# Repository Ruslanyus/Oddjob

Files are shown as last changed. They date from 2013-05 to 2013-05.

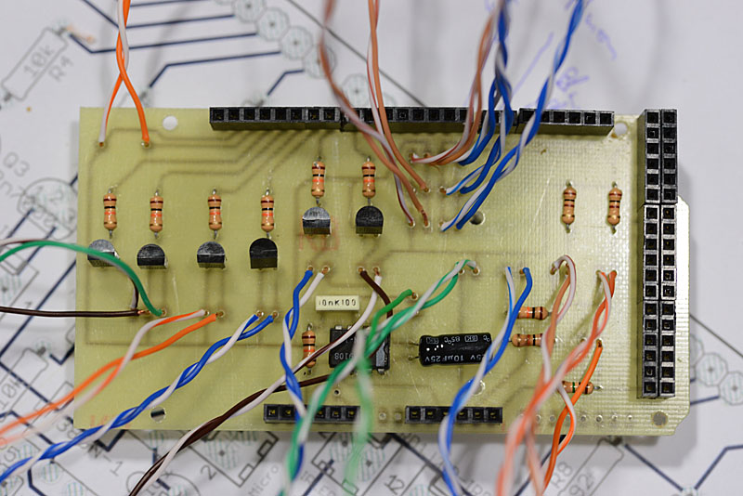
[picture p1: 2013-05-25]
CI-monte-small.jpg

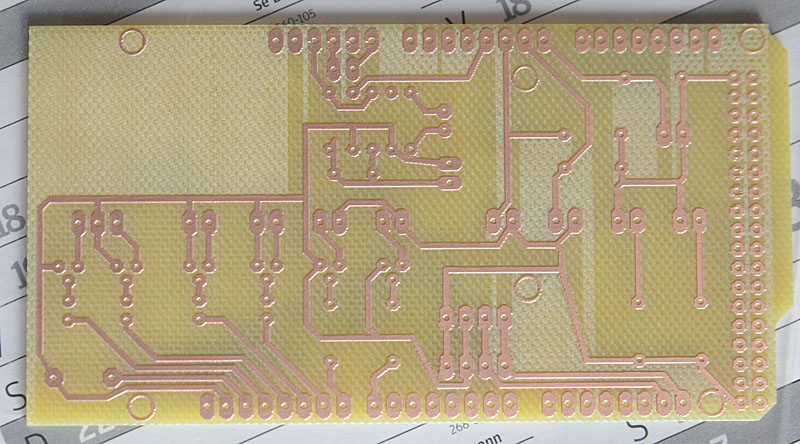
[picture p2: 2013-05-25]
CI-small.jpg

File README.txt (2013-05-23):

Oddjob project is based on the Photoduino project.
My main objective is to add a new interface to this project, I have added a touch screen with several updated.

Logos are stored on the SD card, UTFT library and tools are used to generate logo.

You have to copy logos on RAW format into the root of your SD card.

To do list:
-unbug the display: some case the text is too long and wrote out of display memory, I have to fix this issue

-The date and time module is not coded to log all information with date and time
-luxmeter display information but information is display without presentation.

I publish more information on the www.godreau.fr website with photos.

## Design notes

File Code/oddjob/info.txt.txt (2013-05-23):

arduino port Used:
TFT: 38,39,40,41
touch: 6,5,4,3,2
sd card: D52,50,51+SS

Ports analogics
- sound 4
- ir led1 6
- ir led2 5
- shock 7

ports num:
-buzzer 13
-focus 12
-trigger 11
-flash1 10
-flash2 9
-laser1 8 
-laser2 7

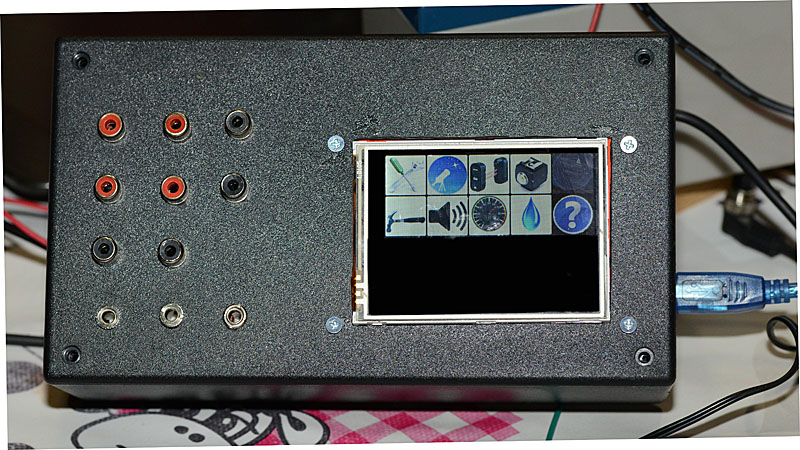
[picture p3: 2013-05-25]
oddjob-small.jpg

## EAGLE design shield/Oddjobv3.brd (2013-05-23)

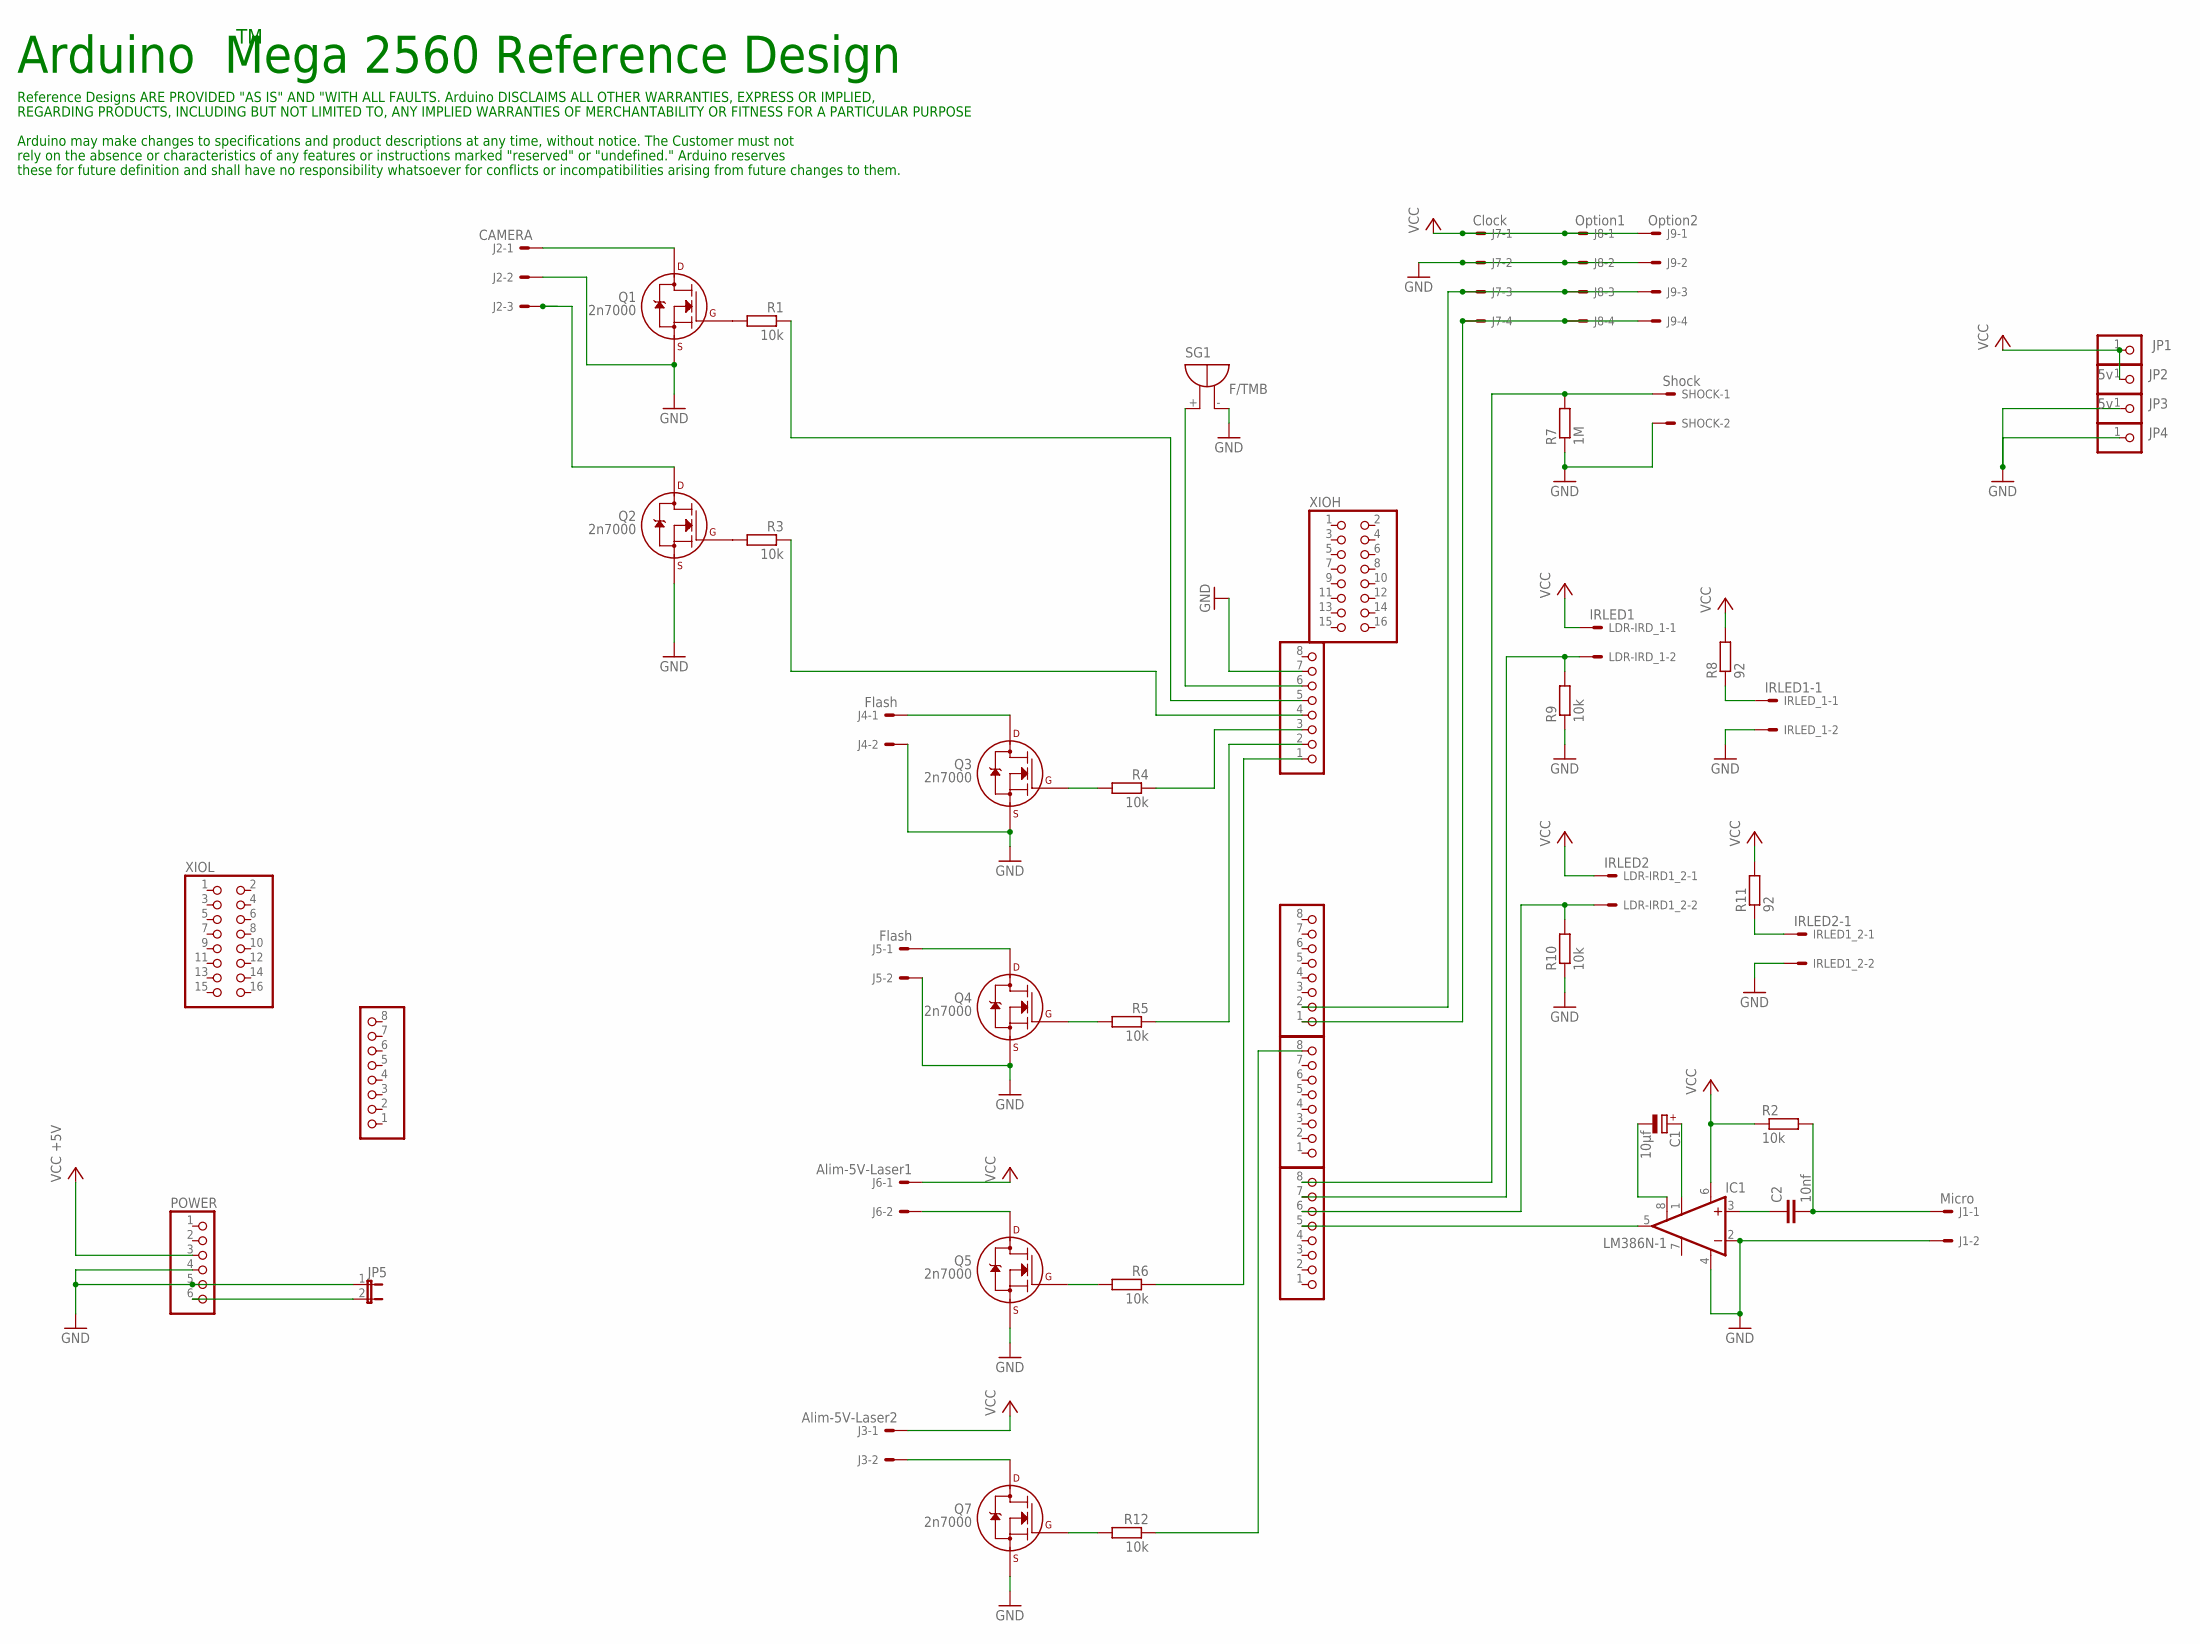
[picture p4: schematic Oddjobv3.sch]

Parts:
ADCH: PINHD-1X8; 1X08
ADCL: PINHD-1X8; 1X08
C1: 10µf; E2,5-6
C2: 10nf; C050-025X075
COMMUNICATION: PINHD-1X8; 1X08
IC1: LM386N-1; DIL08
IRLED1_2: IRLED2-1; 6410-02
IRLED_1: IRLED1-1; 6410-02
J1: Micro; 6410-02
J2: CAMERA; 6410-03
J3: Alim-5V-Laser2; 6410-02
J4, J5: Flash; 6410-02
J6: Alim-5V-Laser1; 6410-02
J7: Clock; 6410-04
J8: Option1; 6410-04
J9: Option2; 6410-04
JP1, JP2: 5v; 1X01
JP3, JP4: PINHD-1X1; 1X01
JP5: JP1E; JP1
LDR-IRD1_2: IRLED2; 6410-02
LDR-IRD_1: IRLED1; 6410-02
POWER: PINHD-1X6; 1X06
PWMH-NUMERIC: PINHD-1X8; 1X08
PWML: PINHD-1X8; 1X08
Q1, Q2, Q3, Q4, Q5, Q7: 2n7000; TO-92
R1, R2, R3, R4, R5, R6, R9, R10, R12: 10k; 0207/7
R7: 1M; 0207/7
R8, R11: 92; 0207/7
SG1: F/TMB
SHOCK: Shock; 6410-02
XIOH: PINHD-2X8; 2X08
XIOL: PINHD-2X8; 2X08

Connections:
GND: IC1.2 (-IN), IC1.4 (GND), IRLED1_2.2, IRLED_1.2, J1.2, J2.2, J4.2, J5.2, J7.2, J8.2, J9.2, JP3.1, JP4.1, JP5.1, POWER.4, POWER.5, PWMH-NUMERIC.7, Q1.1 (S), Q2.1 (S), Q3.1 (S), Q4.1 (S), Q5.1 (S), Q7.1 (S), R7.1, R9.1, R10.1, SG1.-, SHOCK.2
unnamed: Q1.2 (G), R1.2
unnamed: J2.1, Q1.3 (D)
unnamed: C1.+, IC1.1 (GAIN)
unnamed: C1.-, IC1.8 (GAIN)
unnamed: C2.1, IC1.3 (+IN)
unnamed: C2.2, J1.1, R2.2
unnamed: Q2.2 (G), R3.2
unnamed: J2.3, Q2.3 (D)
unnamed: PWMH-NUMERIC.6, SG1.+
unnamed: Q3.2 (G), R4.2
unnamed: J4.1, Q3.3 (D)
unnamed: J6.2, Q5.3 (D)
unnamed: Q4.2 (G), R5.2
unnamed: J5.1, Q4.3 (D)
unnamed: Q5.2 (G), R6.2
unnamed: IRLED_1.1, R8.1
unnamed: ADCL.7, LDR-IRD_1.2, R9.2
unnamed: ADCL.6, LDR-IRD1_2.2, R10.2
unnamed: IRLED1_2.1, R11.1
unnamed: PWMH-NUMERIC.1, R6.1
unnamed: PWMH-NUMERIC.5, R1.1
unnamed: PWMH-NUMERIC.2, R5.1
unnamed: PWMH-NUMERIC.4, R3.1
unnamed: PWMH-NUMERIC.3, R4.1
unnamed: ADCL.5, IC1.5 (OUT)
unnamed: Q7.2 (G), R12.2
unnamed: J3.2, Q7.3 (D)
unnamed: ADCL.8, R7.2, SHOCK.1
unnamed: COMMUNICATION.1, J7.4, J8.4, J9.4
unnamed: PWML.8, R12.1
unnamed: COMMUNICATION.2, J7.3, J8.3, J9.3
unnamed: JP5.2, POWER.6
VCC: IC1.6 (VS), J3.1, J6.1, J7.1, J8.1, J9.1, JP1.1, JP2.1, LDR-IRD1_2.1, LDR-IRD_1.1, POWER.3, R2.1, R8.2, R11.2

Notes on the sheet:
Arduino Mega 2560 Reference Design
Reference Designs ARE PROVIDED "AS IS" AND "WITH ALL FAULTS. Arduino DISCLAIMS ALL OTHER WARRANTIES, EXPRESS OR IMPLIED,
Arduino may make changes to specifications and product descriptions at any time, without notice. The Customer must not
REGARDING PRODUCTS, INCLUDING BUT NOT LIMITED TO, ANY IMPLIED WARRANTIES OF MERCHANTABILITY OR FITNESS FOR A PARTICULAR PURPOSE
rely on the absence or characteristics of any features or instructions marked "reserved" or "undefined." Arduino reserves
these for future definition and shall have no responsibility whatsoever for conflicts or incompatibilities arising from future changes to them.

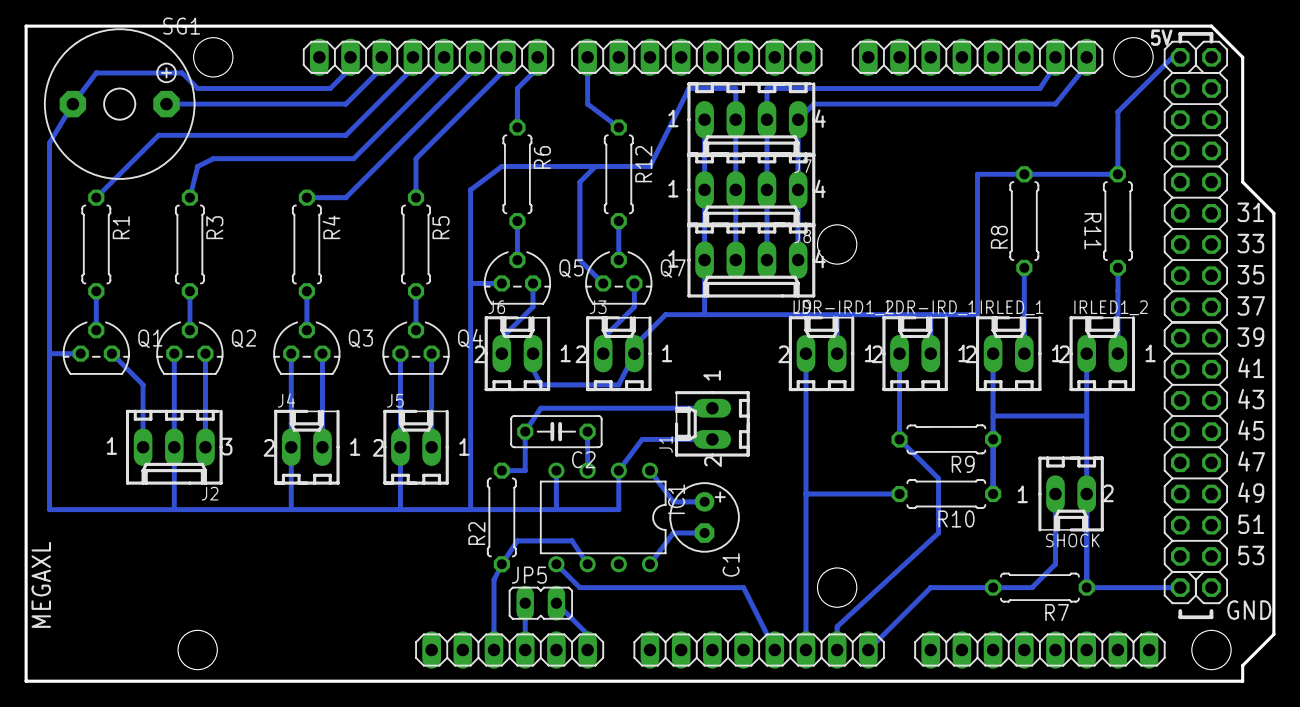
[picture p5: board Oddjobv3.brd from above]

Board: 1 copper layer, 101.6 x 53.3 mm, 49 parts (0 on the bottom side), 34 nets.

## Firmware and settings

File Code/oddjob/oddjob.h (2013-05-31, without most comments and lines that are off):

#define DEFAULT_SHUTTERLAG               100
#define DEFAULT_INTERCICLE_TIME          200
#define DEVICES_FLASHES_SHOOTING_PULSE     1
#define DEVICES_CAMERA_MIRROR_LOCKUP_TIMELIMIT         31000
#include <avr/pgmspace.h>  // For messages in flash memory
#include <EEPROM.h>
#define SIGNATURE_CODE1             0x10 // day
#define SIGNATURE_CODE2             0x03 // month
#define SIGNATURE_CODE3             0x20 // century
#define SIGNATURE_CODE4             0x13 // year of century
#define CODE_MAYOR_VERSION          0x1 // mayor version
#define CODE_MINOR_VERSION          0x13 // minor version
#define DEFAULT_system_useSpeaker                     true
#define DEFAULT_system_flashPulsing                   DEVICES_FLASHES_SHOOTING_PULSE
#define DEFAULT_intervalMode_autofocusTime            0
#define DEFAULT_intervalMode_shutterLagTime           DEFAULT_SHUTTERLAG
#define DEFAULT_intervalMode_useFlash1                false
#define DEFAULT_intervalMode_preFlash1Time            0
#define DEFAULT_intervalMode_useFlash2                false
#define DEFAULT_intervalMode_preFlash2Time            0
#define DEFAULT_intervalMode_preCloseTime             0
#define DEFAULT_intervalMode_intervalUnits            UNITS_SECS
#define DEFAULT_intervalMode_intervalValue            1
#define DEFAULT_intervalMode_numCicles                0
#define DEFAULT_audioTriggerMode_sensorLimit          51
#define DEFAULT_audioTriggerMode_shootingMode         SHOOTINGMODE_NORMAL
#define DEFAULT_audioTriggerMode_autofocusTime        0
#define DEFAULT_audioTriggerMode_shutterLagTime       DEFAULT_SHUTTERLAG
#define DEFAULT_audioTriggerMode_preCloseTime         0
#define DEFAULT_audioTriggerMode_useFlash1            false
#define DEFAULT_audioTriggerMode_preFlash1Time        0
#define DEFAULT_audioTriggerMode_useFlash2            false
#define DEFAULT_audioTriggerMode_preFlash2Time        0
#define DEFAULT_audioTriggerMode_numCicles            0
#define DEFAULT_audioTriggerMode_interCicleTime       DEFAULT_INTERCICLE_TIME
#define DEFAULT_shockTriggerMode_sensorLimit          51
#define DEFAULT_shockTriggerMode_shootingMode         SHOOTINGMODE_NORMAL
#define DEFAULT_shockTriggerMode_autofocusTime        0
#define DEFAULT_shockTriggerMode_shutterLagTime       DEFAULT_SHUTTERLAG
#define DEFAULT_shockTriggerMode_preCloseTime         0
#define DEFAULT_shockTriggerMode_useFlash1            false
#define DEFAULT_shockTriggerMode_preFlash1Time        0
#define DEFAULT_shockTriggerMode_useFlash2            false
#define DEFAULT_shockTriggerMode_preFlash2Time        0
#define DEFAULT_shockTriggerMode_numCicles            0
#define DEFAULT_shockTriggerMode_interCicleTime       DEFAULT_INTERCICLE_TIME
#define DEFAULT_barrierMode_sensorLimit               51
#define DEFAULT_barrierMode_shootingMode              SHOOTINGMODE_NORMAL
#define DEFAULT_barrierMode_autofocusTime             0
#define DEFAULT_barrierMode_shutterLagTime            DEFAULT_SHUTTERLAG
#define DEFAULT_barrierMode_preCloseTime              0
#define DEFAULT_barrierMode_useFlash1                 false
#define DEFAULT_barrierMode_preFlash1Time             0
#define DEFAULT_barrierMode_useFlash2                 false
#define DEFAULT_barrierMode_preFlash2Time             0
#define DEFAULT_barrierMode_numCicles                 0
#define DEFAULT_barrierMode_interCicleTime            DEFAULT_INTERCICLE_TIME
#define DEFAULT_flashSlave_sensorLimit                51
#define DEFAULT_flashSlave_useFlash1                  true
#define DEFAULT_flashSlave_preFlash1Time              0
#define DEFAULT_flashSlave_useFlash2                  true
#define DEFAULT_flashSlave_preFlash2Time              0
#define DEFAULT_astroMode_preCloseTime             0
#define DEFAULT_astroMode_intervalUnits            UNITS_SECS
#define DEFAULT_astroMode_intervalValue            1
#define DEFAULT_astroMode_pauseValue               1
#define DEFAULT_astroMode_numCicles                0
#define DEFAULT_barrier2Mode_sensor1Limit          51
#define DEFAULT_barrier2Mode_sensor2Limit          51
#define DEFAULT_barrier2Mode_distance              10
#define DEFAULT_dropMode_dropCount                 0
#define DEFAULT_dropMode_dropDuration              100
#define DEFAULT_dropMode_dropInterval              500
#define DEFAULT_dropMode_drop2Duration             0
#define DEFAULT_dropMode_dropShooting              100
#define DEFAULT_dropMode_dropPause                 500
#define PINS_BUZZER          13  //(pwm6 pin)
#define PINS_SHUTTER         11  //(digital pin)
#define PINS_AUTOFOCUS       12  //(digital pin)
#define PINS_LASER1          8  //(digital pin)
#define PINS_LASER2          7  //(digital pin)
#define PINS_FLASH1          10 //10 56 = Mega 16 = Duemilanova //(digital pin)
#define PINS_FLASH2          9  //9 55 = Mega 15 = Duemilanova //(digital pin)
#define PINS_LASER           PINS_RESERVED  // alias(digital pin)
#define PINS_SENSOR_SHOCK    61  //(analog pin)
#define PINS_SENSOR_BARRIER1 60  //(analog pin)
#define PINS_SENSOR_BARRIER2 59  //(analog pin)
#define PINS_SENSOR_MIC      58  //(analog pin)
#define UNITS_MS             0  // miliseconds
#define UNITS_SECS           1  // seconds
#define UNITS_MINS           2  // minutes
#define UNITS_HOURS          3  // hours
#define UNITS_DAYS           4  // days
#define UNITS_CICLES         10 // cicles
#define UNITS_US             11 // microseconds
#define SENSOR_MODE_LOWER    0 // for trigg by lower values
#define SENSOR_MODE_HIGHER   1 // for trigg by higher values
#define SHOOTINGMODE_NORMAL           0 // Normal mode
#define SHOOTINGMODE_PREBULB          1 // Prebulb mode
#define SHOOTINGMODE_MIRRORLOCKUP     2 // Mirror lookup mode
#define EEPROM_SIZE         512
#define EE_ADDR_SIGNATURE_CODE1                     0x00 // BYTE
#define EE_ADDR_SIGNATURE_CODE2                     0x01 // BYTE
#define EE_ADDR_SIGNATURE_CODE3                     0x02 // BYTE
#define EE_ADDR_SIGNATURE_CODE4                     0x03 // BYTE
#define EE_ADDR_CODE_MAYOR_VERSION                  0x04 // BYTE
#define EE_ADDR_CODE_MINOR_VERSION                  0x06 // BYTE
#define EE_ADDR_system_useSpeaker                   0x12 // BYTE
#define EE_ADDR_system_flashPulsing                 0x16 // BYTE
#define EE_ADDR_intervalMode_autofocusTime          0x20 // WORD
#define EE_ADDR_intervalMode_shutterLagTime         0x22 // WORD
#define EE_ADDR_intervalMode_useFlash1              0x24 // BYTE
#define EE_ADDR_intervalMode_preFlash1Time          0x26 // WORD
#define EE_ADDR_intervalMode_useFlash2              0x28 // BYTE
#define EE_ADDR_intervalMode_preFlash2Time          0x2A // WORD
#define EE_ADDR_intervalMode_preCloseTime           0x2C // WORD
#define EE_ADDR_intervalMode_intervalUnits          0x2E // BYTE
#define EE_ADDR_intervalMode_intervalValue          0x30 // WORD
#define EE_ADDR_intervalMode_numCicles              0x32 // WORD
#define EE_ADDR_audioTriggerMode_sensorLimit        0x40 // WORD
#define EE_ADDR_audioTriggerMode_shootingMode       0x42 // BYTE
#define EE_ADDR_audioTriggerMode_autofocusTime      0x44 // WORD
#define EE_ADDR_audioTriggerMode_shutterLagTime     0x46 // WORD
#define EE_ADDR_audioTriggerMode_preCloseTime       0x48 // WORD
#define EE_ADDR_audioTriggerMode_useFlash1          0x4A // BYTE
#define EE_ADDR_audioTriggerMode_preFlash1Time      0x4C // WORD
#define EE_ADDR_audioTriggerMode_useFlash2          0x4E // BYTE
#define EE_ADDR_audioTriggerMode_preFlash2Time      0x50 // WORD
#define EE_ADDR_audioTriggerMode_numCicles          0x52 // WORD
#define EE_ADDR_audioTriggerMode_interCicleTime     0x54 // WORD
#define EE_ADDR_shockTriggerMode_sensorLimit        0x60 // WORD
#define EE_ADDR_shockTriggerMode_shootingMode       0x62 // BYTE
#define EE_ADDR_shockTriggerMode_autofocusTime      0x64 // WORD
#define EE_ADDR_shockTriggerMode_shutterLagTime     0x66 // WORD
#define EE_ADDR_shockTriggerMode_preCloseTime       0x68 // WORD
#define EE_ADDR_shockTriggerMode_useFlash1          0x6A // BYTE
#define EE_ADDR_shockTriggerMode_preFlash1Time      0x6C // WORD
#define EE_ADDR_shockTriggerMode_useFlash2          0x6E // BYTE
#define EE_ADDR_shockTriggerMode_preFlash2Time      0x70 // WORD
#define EE_ADDR_shockTriggerMode_numCicles          0x72 // WORD
#define EE_ADDR_shockTriggerMode_interCicleTime     0x74 // WORD
#define EE_ADDR_barrierMode_sensorLimit             0x80 // WORD
#define EE_ADDR_barrierMode_shootingMode            0x82 // BYTE
#define EE_ADDR_barrierMode_autofocusTime           0x84 // WORD
#define EE_ADDR_barrierMode_shutterLagTime          0x86 // WORD
#define EE_ADDR_barrierMode_preCloseTime            0x88 // WORD
#define EE_ADDR_barrierMode_useFlash1               0x8A // BYTE
#define EE_ADDR_barrierMode_preFlash1Time           0x8C // WORD
#define EE_ADDR_barrierMode_useFlash2               0x8E // BYTE
#define EE_ADDR_barrierMode_preFlash2Time           0x90 // WORD
#define EE_ADDR_barrierMode_numCicles               0x92 // WORD
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

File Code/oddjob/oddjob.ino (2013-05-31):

// oddjob (C)2013 Ludovic Godreau
// web: http://www.godreau.fr
//
// This program is a test for new photoduino interface
// This program requires UTFT_tinyFAT, UTFT v1.2 or higher, 
// as well as the tinyFAT v3.0 or higher.
//
// The image files must be present in the root folder 
// of a FAT16 formatted SDcard in the module cardslot.
//

#include <tinyFAT.h>
#include <UTFT.h>
#include <UTFT_tinyFAT.h>
#include <UTouch.h>
#include "oddjob.h"
#include <EEPROM.h>
#include <Wire.h> //IIC
#include <math.h> //IIC
 
// Declare which fonts we will be using
extern uint8_t SmallFont[];
extern uint8_t BigFont[];
extern uint8_t SevenSegNumFont[];



// Global variables
int          BH1750address = 0x23;      //luxmeter
byte         buff[2];                   //lux

// System config in ram
boolean      system_useSpeaker;
unsigned int system_flashPulsing;


// Interval mode config in ram
unsigned int intervalMode_autofocusTime;
unsigned int intervalMode_shutterLagTime;
boolean      intervalMode_useFlash1;
unsigned int intervalMode_preFlash1Time;
boolean      intervalMode_useFlash2;
unsigned int intervalMode_preFlash2Time;
unsigned int intervalMode_preCloseTime;
byte         intervalMode_intervalUnits;
unsigned int intervalMode_intervalValue;
unsigned int intervalMode_numCicles;

// Audio trigger mode config in ram
unsigned int audioTriggerMode_sensorLimit;
byte         audioTriggerMode_shootingMode;
unsigned int audioTriggerMode_autofocusTime;
unsigned int audioTriggerMode_shutterLagTime;
unsigned int audioTriggerMode_preCloseTime;
boolean      audioTriggerMode_useFlash1;
unsigned int audioTriggerMode_preFlash1Time;
boolean      audioTriggerMode_useFlash2;
unsigned int audioTriggerMode_preFlash2Time;
unsigned int audioTriggerMode_numCicles;
unsigned int audioTriggerMode_interCicleTime;

// Shock trigger mode config in ram
unsigned int shockTriggerMode_sensorLimit;
byte         shockTriggerMode_shootingMode;
unsigned int shockTriggerMode_autofocusTime;
unsigned int shockTriggerMode_shutterLagTime;
unsigned int shockTriggerMode_preCloseTime;
boolean      shockTriggerMode_useFlash1;
unsigned int shockTriggerMode_preFlash1Time;
boolean      shockTriggerMode_useFlash2;
unsigned int shockTriggerMode_preFlash2Time;
unsigned int shockTriggerMode_numCicles;
unsigned int shockTriggerMode_interCicleTime;

// Barrier mode config in ram
unsigned int barrierMode_sensorLimit;
byte         barrierMode_shootingMode;
unsigned int barrierMode_autofocusTime;
unsigned int barrierMode_shutterLagTime;
unsigned int barrierMode_preCloseTime;
boolean      barrierMode_useFlash1;
unsigned int barrierMode_preFlash1Time;
boolean      barrierMode_useFlash2;
unsigned int barrierMode_preFlash2Time;
unsigned int barrierMode_numCicles;
unsigned int barrierMode_interCicleTime;

// Flash slave config in ram
unsigned int flashSlave_sensorLimit;
boolean      flashSlave_useFlash1;
unsigned int flashSlave_preFlash1Time;
boolean      flashSlave_useFlash2;
unsigned int flashSlave_preFlash2Time;

byte         flashSlave_shootingMode;
unsigned int flashSlave_autofocusTime;
unsigned int flashSlave_shutterLagTime;
unsigned int flashSlave_preCloseTime;

// astro  mode config in ram
unsigned int astroMode_preCloseTime;
byte         astroMode_intervalUnits;
unsigned int astroMode_intervalValue;
unsigned int astroMode_pauseValue;
unsigned int astroMode_numCicles;

// Barrier2 mode config in ram
unsigned int barrier2Mode_sensor1Limit;
unsigned int barrier2Mode_sensor2Limit;
unsigned int barrier2Mode_distance;

// water mode config in ram
unsigned int dropMode_dropCount;
unsigned int dropMode_dropDuration;
unsigned int dropMode_dropInterval;
unsigned int dropMode_drop2Duration;
unsigned int dropMode_dropShooting;
unsigned int dropMode_dropPause;

//unsigned int system_useSpeaker=0;
//unsigned int system_flashPulsing=10;
unsigned int system_autofocusTime=43;
unsigned int system_shutterLagTime=0;


// Variables used on interrupt mode
volatile boolean cancelFlag = false;    // Flag used to abort interrupt mode



UTFTtf   myGLCD(ITDB32S, 38, 39, 40, 41);   // Remember to change the model parameter to suit your display module!
UTouch   myTouch(6,5,4,3,2);

int picsize_x, picsize_y;

word res;



int debug=1;
void setup()
{
  myGLCD.InitLCD();
  myGLCD.clrScr();
  file.initFAT(SPISPEED_VERYHIGH);
  myGLCD.setColor(255,255,255);
  myGLCD.setFont(SmallFont);
  picsize_x=myGLCD.getDisplayXSize();
  picsize_y=myGLCD.getDisplayYSize();
  myTouch.InitTouch();
  myTouch.setPrecision(PREC_MEDIUM);

// Initialize serial communication 
  Serial.begin(115200);
  Serial.println();

  // Pinmode inputs
  pinMode(PINS_SENSOR_SHOCK, INPUT); 
  pinMode(PINS_SENSOR_BARRIER1, INPUT);
  pinMode(PINS_SENSOR_BARRIER2, INPUT);
  pinMode(PINS_SENSOR_MIC, INPUT);
  
  // Pinmode outputs
  pinMode(PINS_SHUTTER, OUTPUT);
  pinMode(PINS_AUTOFOCUS, OUTPUT);
  pinMode(PINS_FLASH1, OUTPUT);
  pinMode(PINS_FLASH2, OUTPUT);
  pinMode(PINS_LASER1, OUTPUT);
  pinMode(PINS_LASER2, OUTPUT);
  
  pinMode(PINS_BUZZER, OUTPUT);
  //pinMode(PINS_RESERVED, OUTPUT);
  
  Wire.begin();  //IIC

  
 // Initialize config
  config_init(); 
}

void loop()
{
  
  res=main_menu();
  switch (res)
  {
    case 0:
    menu_conf_system();
    config_saveBackup_system();
    break;
    case 1:
    menu_astro();
    break;
    case 2:
    menu_barrier();
    break;
    case 3: //flash slave
    menu_slave();
    break;
    case 4:
      menu_interval();
    break;
    case 5: //shock
     menu_shock();
    break;
    case 6: //audio
      menu_audio();
    break;
    case 7: //speed
      menu_2barrier();
    break;
     case 8: //water
      menu_water();
    break;
    case 9: //clean
    clean_mode();
    break;
    case 10: //lux meter
    lux_mode();
    break;

    case 11: //help
    help_menuP1();
    break;
  }
 
}

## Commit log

2013-05-23 Beta version
    Beta version: running but bugs could be present and few functionalities
    are not finish or validated
    [Oddjobv3.brd, Oddjobv3.sch]
2013-05-31 Add clean mode for solenoid
    Add clean mode for solenoid and Lux meter mode
2013-05-31 Release 1.3
    Bug fix and source cleanup
    [config_manager.ino, devices_manager.ino, functions_utils.ino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]
